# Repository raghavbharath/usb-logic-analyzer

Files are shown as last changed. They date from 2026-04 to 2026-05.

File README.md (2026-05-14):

# ECE692 Final Project - USB Digital Logic Analyzer

Main repository: https://github.com/ragusauce4357/ece692-final-project

**Group Members:** Raghav Bharathan (ragusauce4357), Arnav Revankar (avr34), Gonzalo Villanueva, William Dougherty (Will35084), Bryan Galecio (bryangalecio04)

This project is a custom USB logic analyzer built around two STM32F446RE Nucleo boards, developed as our final project for ECE 692 at NJIT. The system captures digital signals from an external device under test, decodes UART, SPI, I2C, and CAN protocols using a Go signal decoder, and visualizes the results in real time through a Python GUI.

## How It Works

The transmitter Nucleo generates test signals over UART, SPI, I2C, and CAN. The receiver Nucleo samples up to 8 digital channels simultaneously at 1MHz using DMA-driven GPIO capture, packages the raw samples into packets, and streams them to a host PC over USB CDC. A Go application reads the packet stream, decodes UART, SPI, and I2C from the raw samples, and forwards the results to a Python GUI over TCP. CAN frames are decoded inside the STM32 hardware itself by the bxCAN peripheral and forwarded directly. 

## Repository and Branch Structure

Note: This repository is organized across several feature branches, with each of us making contributions in different areas. The `master` branch contains the integrated codebase including the firmware configured for 10kHz sampling over ST-Link USART, which was used during final testing and demonstration. The 1MHz USB CDC configuration and other work can be found in the individual feature branches (`feature/stm32-firmware`, `feature/SignalDecoder`, `feature/GUI`, `feature/PCB`, `feature/3DEnclosure`). The `feature/test` branch contains the final snapshot used during the live demo.

```
firmware-receiver/     # STM32 receiver firmware (STM32CubeIDE)
firmware-transmitter/  # STM32 transmitter firmware
SignalDecoder/         # Go signal decoder application
gui/src/               # Python GUI
PCB/                   # KiCad schematic and PCB layout
enclosure/             # 3D printable STL files
docs/                  # Datasheets and reference manuals
```

### Firmware

The receiver firmware runs on an STM32F446RE at 168MHz. TIM1 generates a 1MHz update event that triggers DMA2 on each tick. The DMA reads the lower byte of GPIOC (PC0-PC7) into a 1024-byte circular ping-pong buffer. When the first half fills, an interrupt fires and the firmware packages bytes 0-511 into a 516-byte logic packet with a 2-byte header, sequence number, and XOR checksum, then sends it over USB CDC. The second half fires the same way. This design keeps sampling continuous with no gaps.

CAN is handled separately. The bxCAN peripheral runs at 500kbps and decodes incoming frames entirely in hardware, delivering a clean frame (ID, DLC, data bytes) to an RX interrupt handler. The firmware packages this into a variable-length CAN packet and sends it over USB CDC alongside the logic packets.

The transmitter firmware runs the same clock config and outputs test signals in a loop every second: UART at 115200 baud, SPI at ~164kHz, I2C to a dummy address (0x52), and a CAN frame with ID 0x123 and payload `0xCAFEBABEDEADBEEF`.

Packet formats:
- Logic: `[0xAA][0xBB][seq][512 bytes][XOR checksum]` = 516 bytes
- CAN: `[0xCC][0xDD][seq][ID_H][ID_L][DLC][0-8 data bytes][XOR checksum]` = variable length

### Go SignalDecoder

The SignalDecoder reads the USB serial stream from the receiver. A `ReadByteStream` goroutine reads into a 1024-byte buffer and pushes raw byte slices into a buffered channel. A `Run` coordinator consumes from the channel, scans for `0xAA 0xBB` or `0xCC 0xDD` headers using a pending accumulation slice to handle packets that span across reads, validates XOR checksums, and detects dropped packets via sequence number wraparound. Logic packets go to the UART, SPI, and I2C decoders. CAN packets are forwarded directly to Python over TCP.

CLI flags: `--port`, `--protocol`, `--pins`, `--duration`

### Python GUI

The GUI launches the Go binary as a subprocess with the appropriate CLI arguments, then connects to its TCP socket to receive decoded data. A background thread parses incoming packets and emits Qt signals to the main thread.

The waveform view shows 8 digital channels plus a synthetic CAN row reconstructed from decoded frame timestamps and DLC. Features include a crosshair cursor, a permanent multi-pair measurement tool with delta-time and frequency readout, a vertical scrollbar, protocol decode annotations color-coded by type, and a CAN decode table. Captures can be saved and loaded as JSON.

Run in simulator mode (no hardware needed, but a few tweaks might need to be made to the code):
```
python gui/src/gui.py --test
```

### PCB

The PCB is a breakout shield that plugs onto both Nucleo boards simultaneously via their morpho headers. It carries a TXS0108E 8-channel bidirectional level shifter for the probe inputs, two SN65HVD230 CAN transceivers (one per Nucleo), per-channel 1kohm series resistors and BAT85 Schottky diodes for overvoltage protection, 4.7kohm I2C pull-ups, a 10-pin probe header, a CANH/CANL screw terminal, and 120ohm CAN termination resistors at each bus end. The schematic is split into receiver and transmitter sub-sheets under a hierarchical root sheet in KiCad.

### Enclosure

3D-printable STL files for a custom enclosure are in `enclosure/`.

## Dependencies

Python:
```
pip install -r gui/src/requirements.txt
```

Go:
```
cd SignalDecoder && go build
```

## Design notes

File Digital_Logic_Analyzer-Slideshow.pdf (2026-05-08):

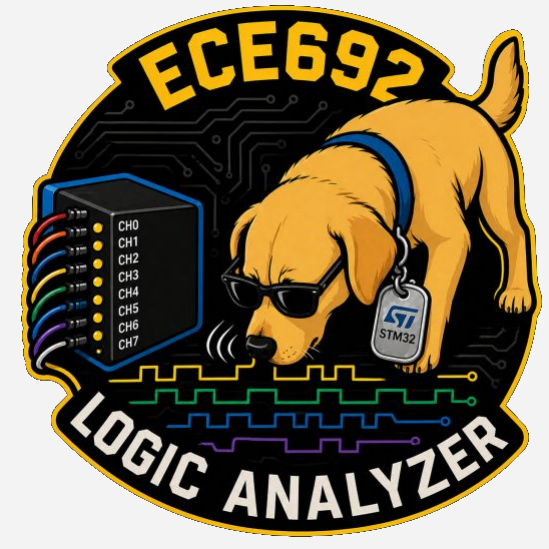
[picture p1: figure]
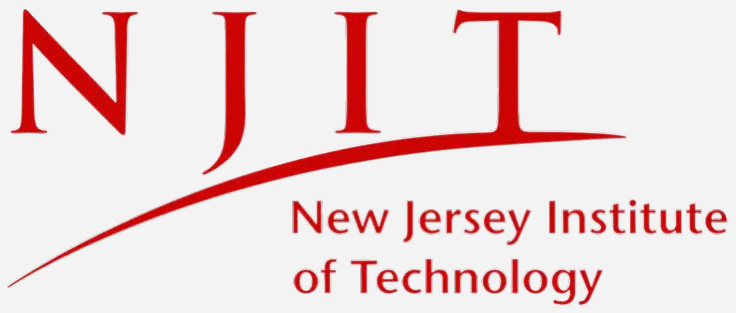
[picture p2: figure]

# Digital Logic Analyzer

By: Arnav Revankar, Gonzalo Villanueva, Raghav Bharathan, William Dougherty, Bryan Galecio

# Agenda

2

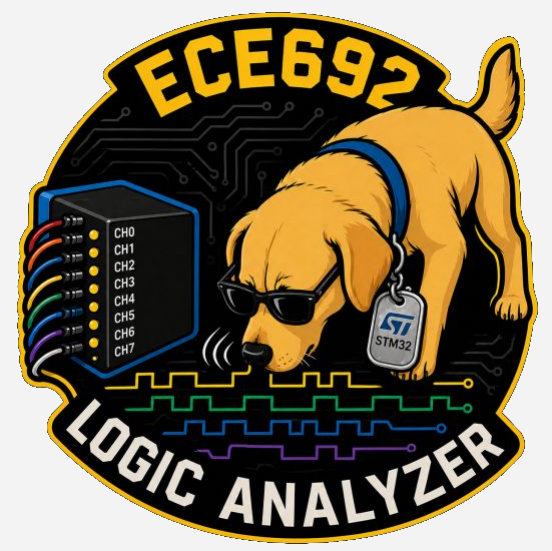
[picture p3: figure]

### - Problem Statement - Project Objectives & Specifications - Components & Cost - System Overview - Code Overview - GUI Overview - Conclusion

# Problem Statement

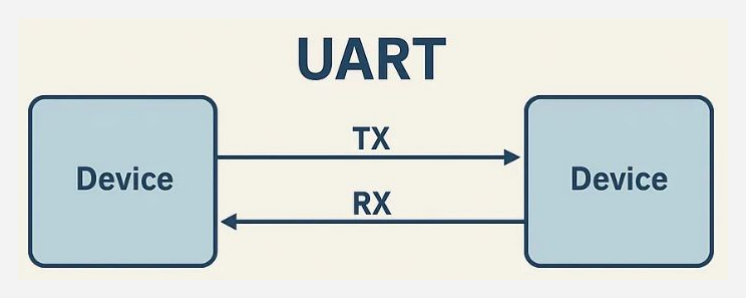
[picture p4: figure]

### - Digital Communication

- UART, SPI, I²C, CAN

### - Challenges within Embedded Systems

- Different protocols use varying frame structures and bit lengths, requiring precise decoding
- Accurate communication depends on strict clocking or synchronization between transmitter and receiver
- Bit mismatches, noise, or misaligned decoding can cause undetected data corruption

### - Digital Logic Analyzer (SOLUTION)

- Tool that captures and visualizes digital signals over time

3

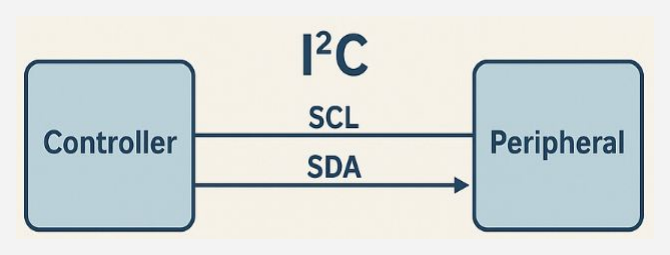
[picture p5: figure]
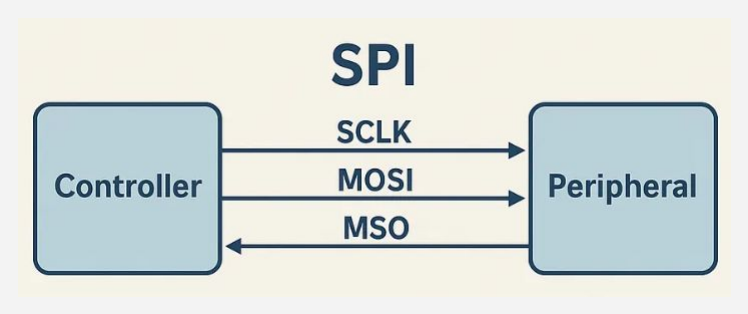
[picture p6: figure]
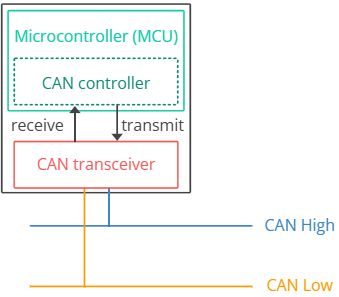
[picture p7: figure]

# Project Objectives & Specifications

- Build an 8-channel Digital Logic Analyzer using GPIO inputs - Use internal timer & DMA to sample signals at a fixed rate, offloading the CPU - Use double buffering to continuously capture and store data without sample loss - Stream data to a PC over USB with basic error detection (sequence numbers + checksum) - Develop a PC GUI for real-time waveform visualization and basic protocol decoding (UART, SPI, I2C, CAN) - Design a PCB layout optimized for low noise, higher sample rate, and system compatibility

4

# Components & Cost

5

Component | Quantity | Cost
NUCLEO-F446RE | 1 | $14.53
SN65HVD230 Can Bus Transceiver | 1 | $2.52
TXS0108E 8-Bit Bi-Directional Level-Shifter | 1 | $1.69
USB-C Socket | 1 | $1.32
Custom PCB | 1 | $9

### Total Cost: $29.06

# System Overview (Block Diagram & Software Pipeline)

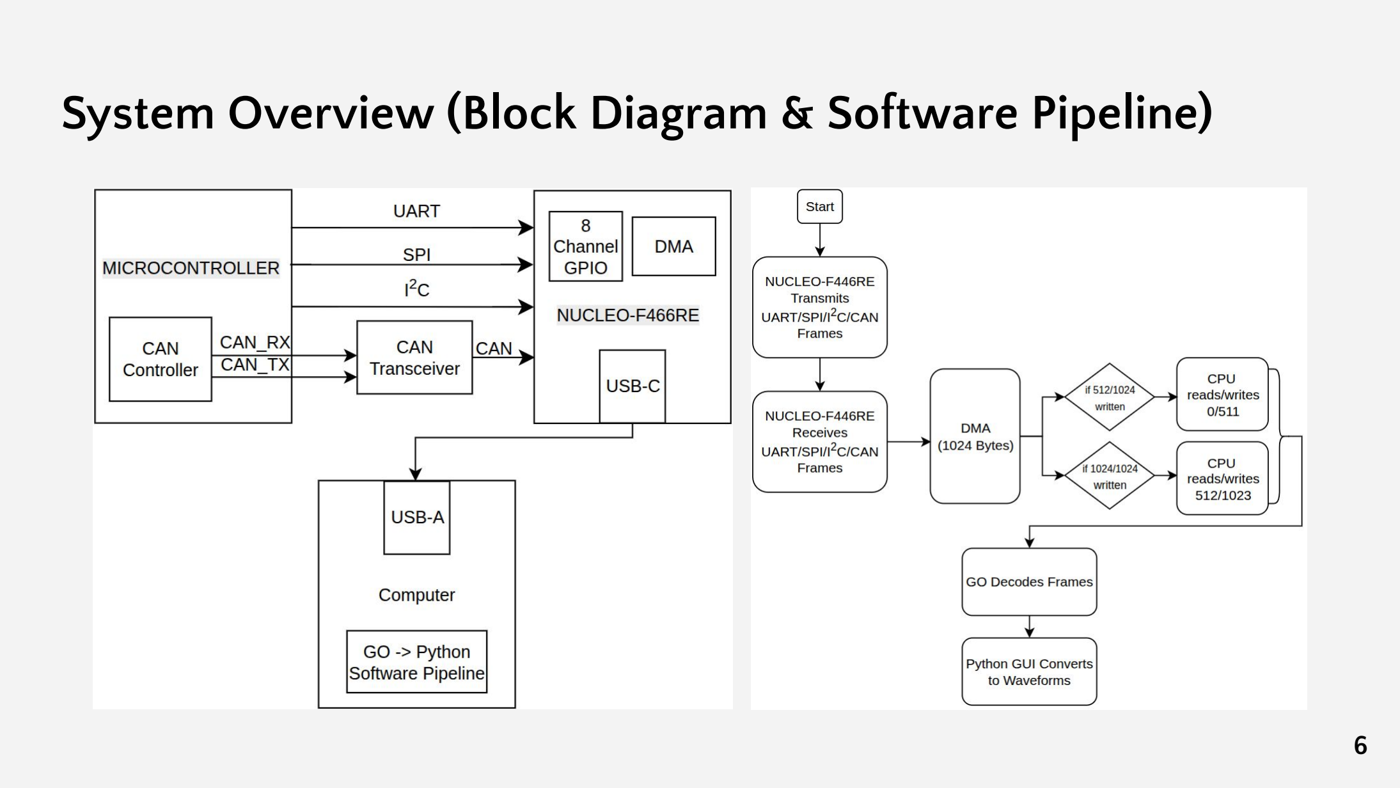
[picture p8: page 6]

6

# System Overview (Schematic)

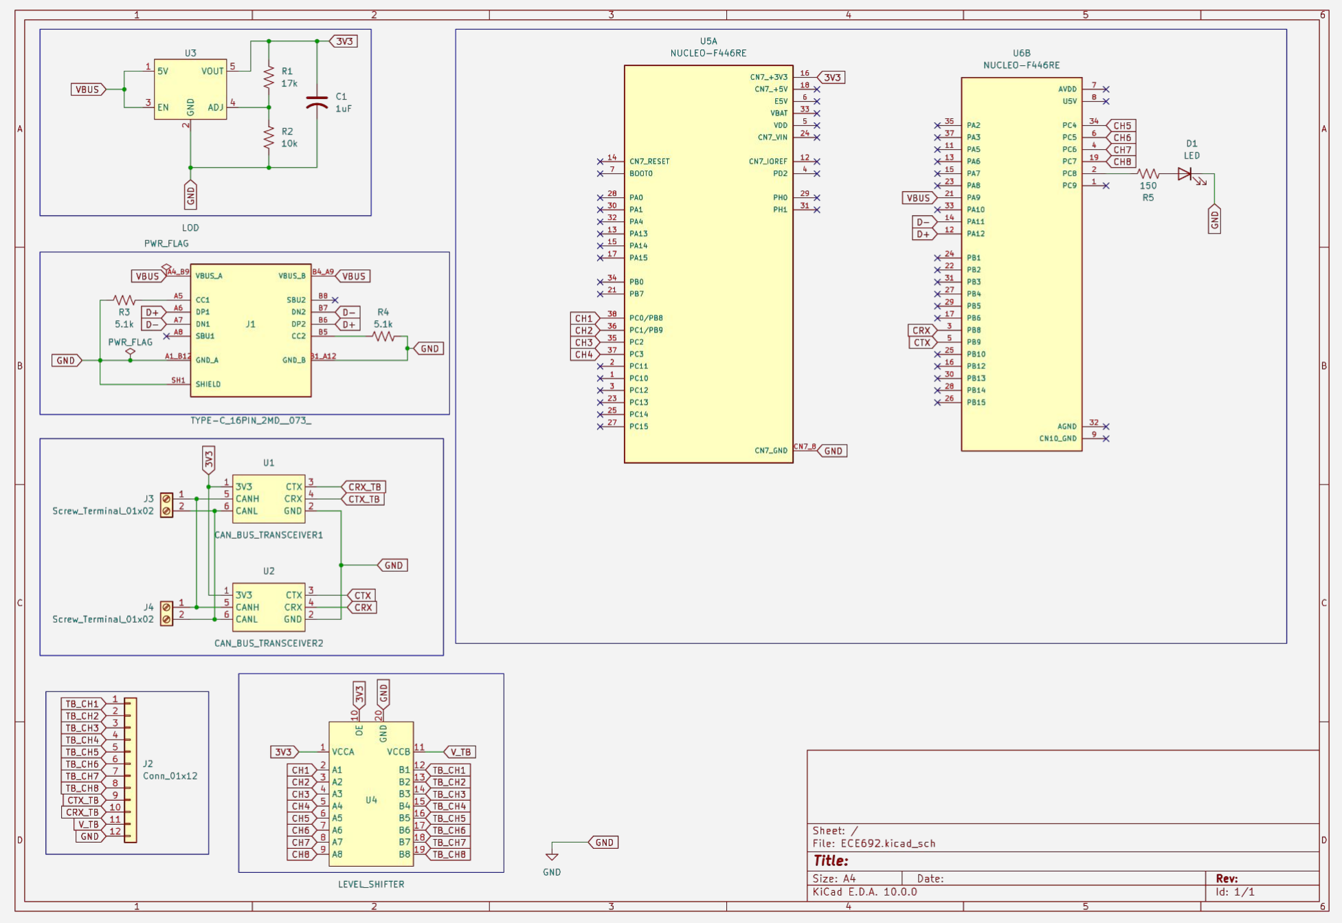
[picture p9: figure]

7

# System Overview (PCB Diagram)

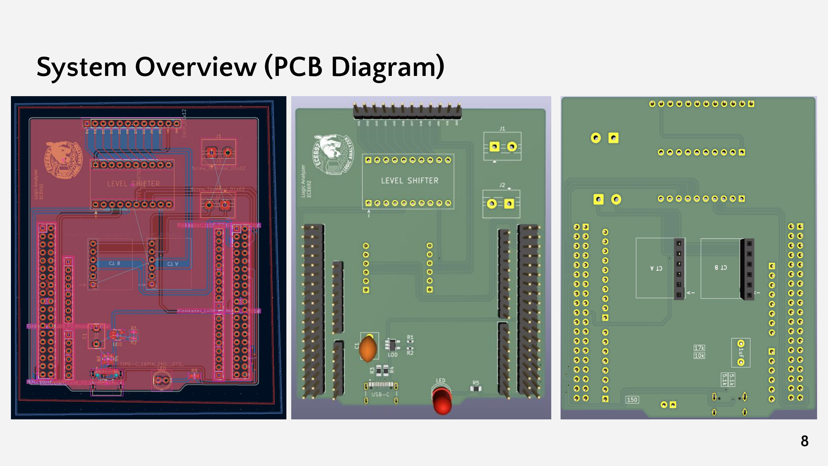
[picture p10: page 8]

8

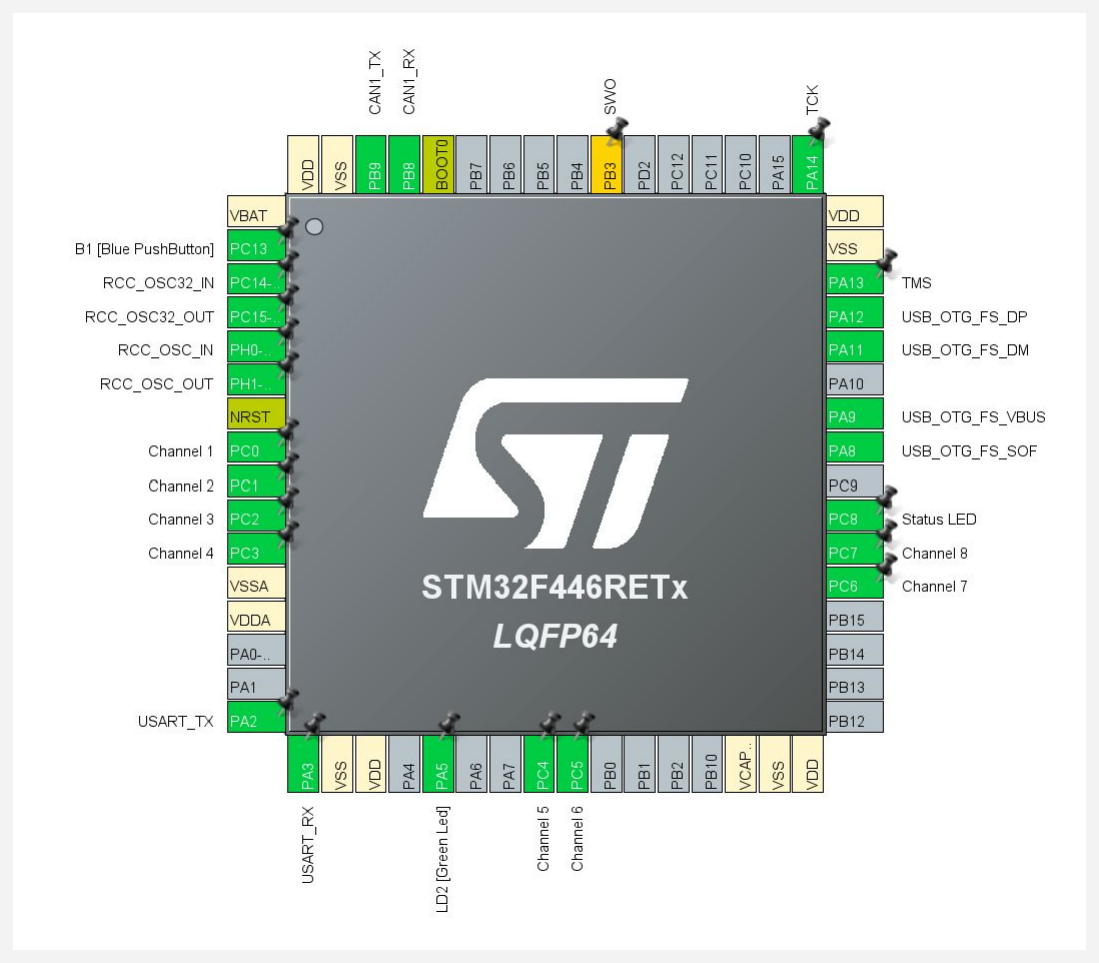
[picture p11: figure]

# STM32 CubeMX Configuration

System Clock
- HSE (8MHz crystal), PLL: PLLM=4, PLLN=168, PLLP=2 → 168MHz HCLK (max)
- APB1 = 42MHz (/4), APB2 = 84 MHz (/2)

TIM1 - Sampling Clock

- Prescaler=99, Period=167 → 10kHz sample rate
- Master output trigger (TRGO) triggers the update for the DMA.

DMA2

- Source: GPIOC→IDR | Destination: dma_buf
- Circular, byte→byte, High priority
- Half and Full transfer interrupts enabled

bxCAN1
- | PSC = 6, BS1 = 11TQ, BS2 = 2TQ → 500kbps, PB8/PB9, RX FIFO0 interrupt is enabled | 9
| NVIC Priorities
| ● DMA2 Stream5: Priority 0 (highest) ● USB: Priority 1 ● bxCAN RX0: Priority 1

# STM32 Sniffer Firmware Pseudocode Overview

CONFIGURE:
GPIO PC0 - PC7: 8-channel digital inputs
TIM1: 10kHz sampling clock
DMA2 Stream5: Circular buffer to store samples USART2: 115200 baud (ST-link to PC)

START TIM1
START DMA
Source: GPIOC input register (all 8 channels)
Destination: Ping-Pong buffer with 2 512 byte Data Chunks = 1024 bytes When the DMA is half-full: flag send_first_half = 1
When the DMA is full: flag send_second_half = 1
LOOP:
IF first half of DMA buffer is ready:
SEND first half of samples to PC
IF second half of DMA buffer is ready:
SEND second half of samples to PC | 10

# STM32 Sniffer Firmware bxCAN Pseudocode Overview

CONFIGURE bxCAN1:

Filter: Accept-all (mask = 0000, bank = 0)

Mode: Normal

START CAN peripheral

Enable RX0 FIFO Interrupt

ON INTERRUPT - if frame received:

READ from FIFO:

StdId → 11-bit CAN ID

DLC → data length (0–8 bytes)

Data[] → payload

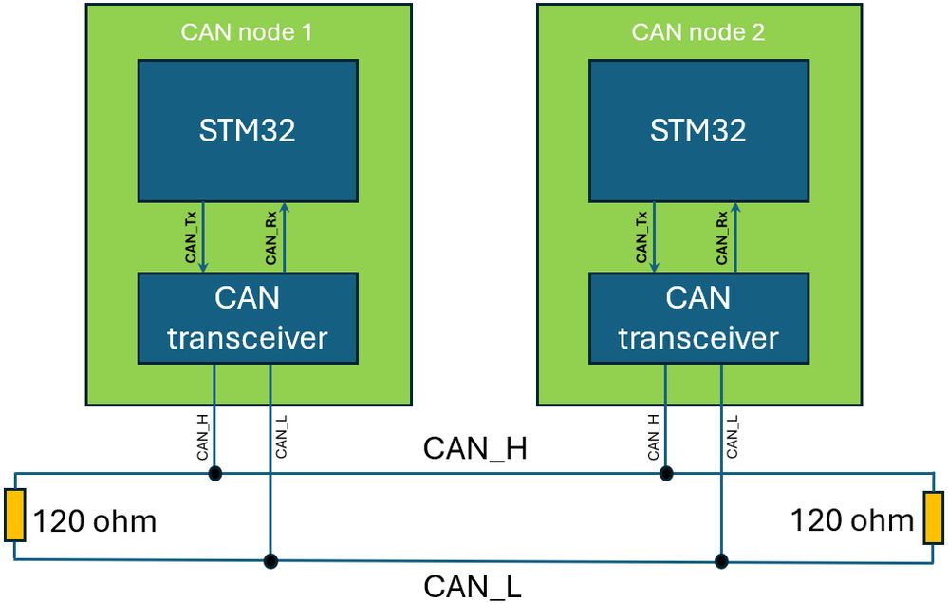
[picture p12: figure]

BUILD packet: [0xCC][0xDD][seq][ID_H][ID_L][DLC][data][XOR checksum]
TRANSMIT over USART2 → PC | 11

# Decoding the Protocols

- For packet decoding, we used Go.
- Packets arrive from the STM via a COM port (COMx or /dev/ttyx) in custom 516 byte format:
- [Header 0xAABB] [Sequence num (0 - 255)] [512 Channel Samples] [XOR Checksum]
- The Go decoder reads these packets off the COM port, and will:
- Validate the checksum (XOR all received bytes)
- Validate the sequence number. If invalid then a packet was dropped.
- Reconstruct the channel waveforms, and decode the chosen signal protocol.
- Currently, UART, I2C, and SPI are supported, and tested with simulated packets
- However, only UART was tested, due to sample rate constraints.

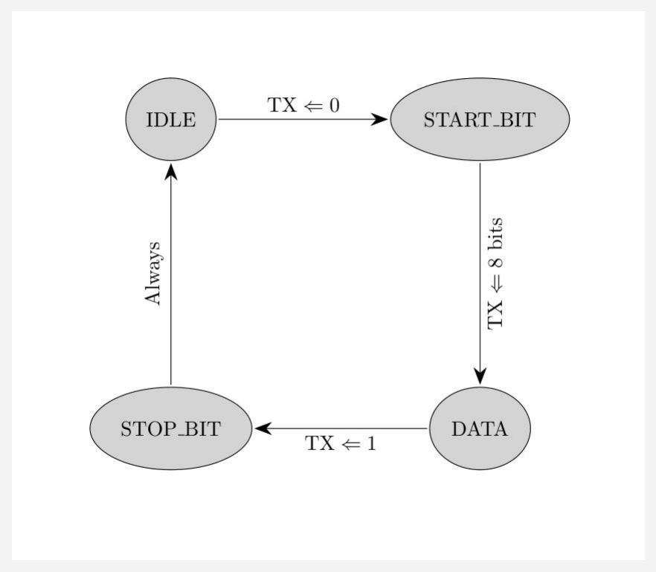
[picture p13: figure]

12

- Waveform data and decoded packets then sent to Python GUI via
network socket.

# GUI Overview

### - Uses: - Python ■ PyQT5 ■ PyQTGraph ■ Numpy ■ Time

13

### Pseudocode:

### - Captures COM port data through Go (transport.py) - Reads packets / parses them (packets.py) - Plots the waveforms next to their corresponding labels(display.py) - Opens an application with logical analyzer tool (gui.py)

# GUI Overview (continued)

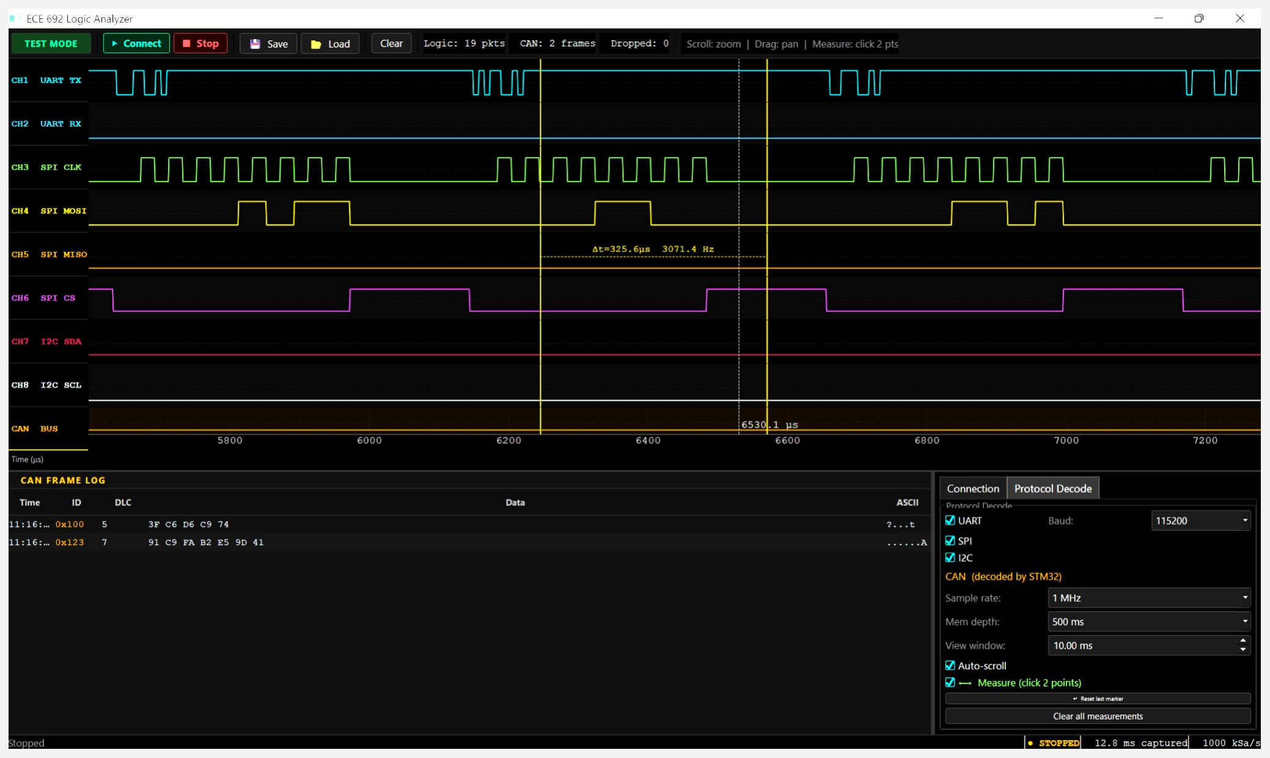
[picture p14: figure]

14

Two main regions: - Top: - Toolbar - Waveforms / Labels - Bottom: - Can Frame Log - Settings Panel - Protocol Decode Panel - Connection Panel - Status Bar

# GUI Overview (continued)

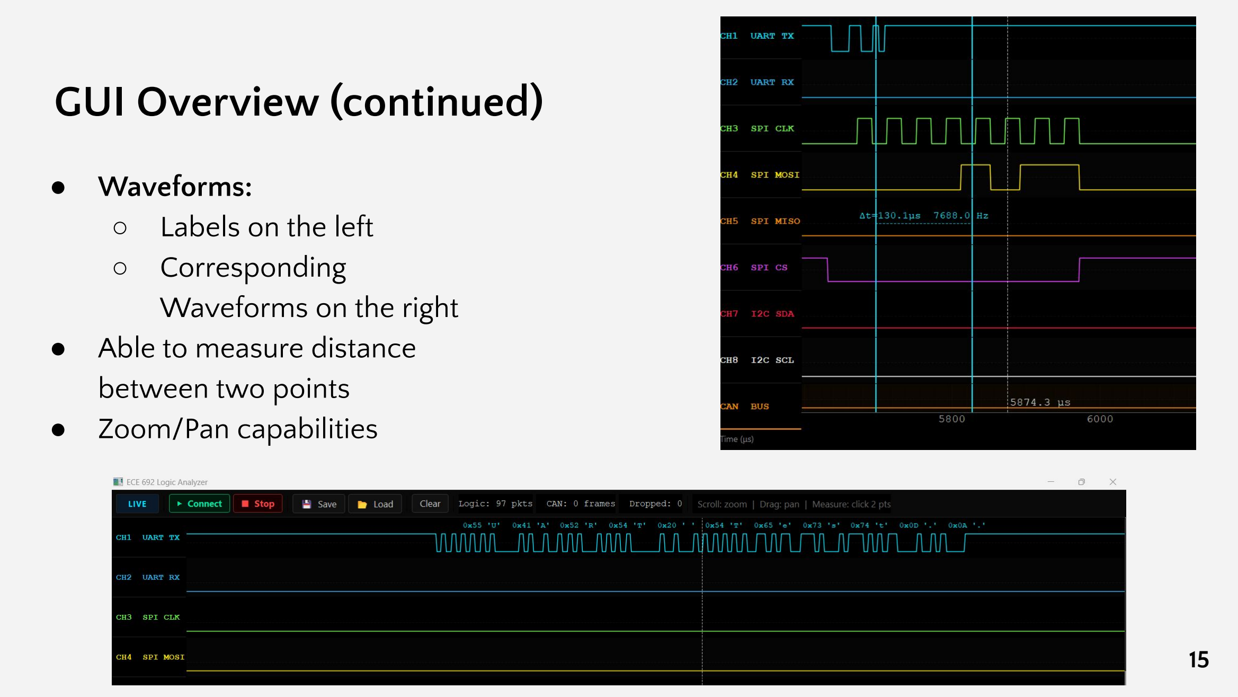
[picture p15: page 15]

15

### - Waveforms: - Labels on the left - Corresponding Waveforms on the right - Able to measure distance between two points - Zoom/Pan capabilities

# Conclusion

### - Challenges

- ST-Link Bottleneck During Prototyping
■ Low throughput caused data transfer issues and incorrect decoding; resolved with custom PCB + improved USB interface

### - Future Improvements

- Switch from ST-Link USART to USB CDC from the PCB connector. This will enable 1MHz sampling and 115200 baud rate for UART decoding, which would reduce noise and provide better accuracy.
- Improve the decoded frame sizing in the GUI and potentially move one of the CAN transceivers outside the PCB for CANH/CANL compatibility.
- Implement compatibility for protocols outside the scope of what we have so far (UART, SPI, I²C, CAN) and also with Sigrok and Pulseview’s byte structure format.

16

# Questions?

17

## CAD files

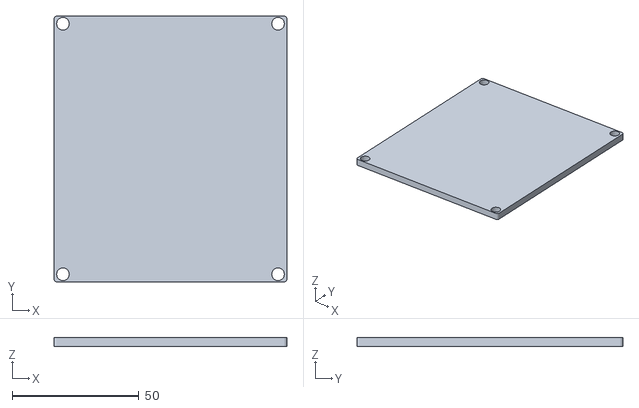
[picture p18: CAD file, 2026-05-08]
enclosure/Lid.stl
92.0 x 105.0 x 3.50

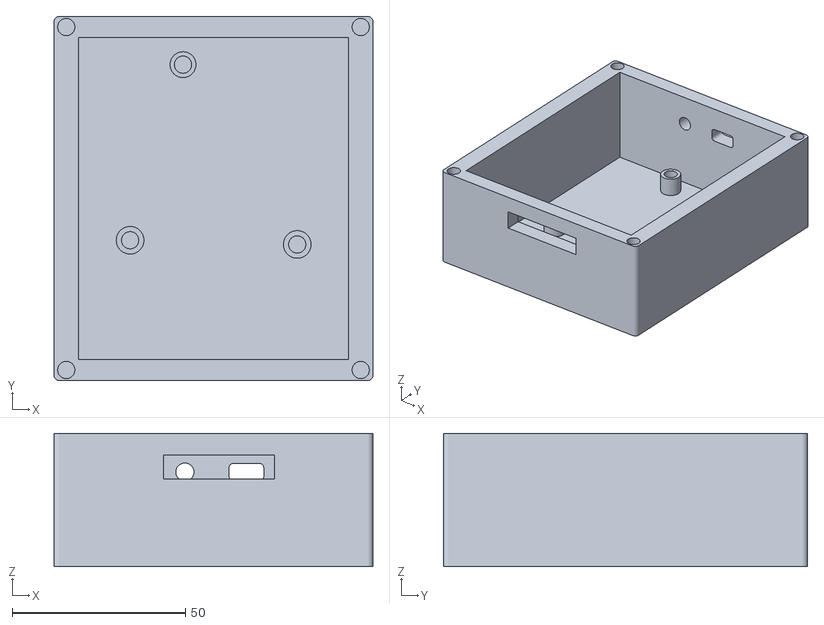
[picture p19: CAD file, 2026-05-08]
enclosure/Enclosure.stl
92.0 x 105.0 x 38.5

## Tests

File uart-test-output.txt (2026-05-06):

PS C:\Users\ragha\OneDrive\Desktop\ECE692-Final-Project\SignalDecoder> go run . --port COM4 --protocol UART --pins tx1rx2 --sr 10000 --duration 5000 --baud 2400
2026/05/06 01:35:33 [GetConfig]: Parsing arguments...
2026/05/06 01:35:33 [parsePins]: Parsing pins argument...
2026/05/06 01:35:33 [parseUART]: Parsing UART pins...
2026/05/06 01:35:33 [parseUART]: Using channels 1, 2, for tx and rx
2026/05/06 01:35:33 [parseUART]: Completed UART pin parsing
2026/05/06 01:35:33 [GetConfig]: CLI argument error checking complete.
2026/05/06 01:35:33 [print] Current configuration:
2026/05/06 01:35:33 [print]   Port:        COM4
2026/05/06 01:35:33 [print]   Duration:    5000.000000
2026/05/06 01:35:33 [print]   Sample Rate: 0x2710
2026/05/06 01:35:33 [print]   Protocol:    1
2026/05/06 01:35:33 [print]   Pins:        0x1200
2026/05/06 01:35:33 [Run]: Running for 5000 ms
2026/05/06 01:35:33 [ReadByteStream]: Opened port.
2026/05/06 01:35:33 [ReadByteStream]: Started streaming from COM4...
2026/05/06 01:35:33 [parseLogicPacket]: Logic packet seq=179
2026/05/06 01:35:33 [DecodeUART]: Beginning UART Decoding...
2026/05/06 01:35:33 [DecodeUART]: UART Decoding complete
2026/05/06 01:35:33 [parseLogicPacket]: Logic packet seq=180
2026/05/06 01:35:33 [DecodeUART]: Beginning UART Decoding...
2026/05/06 01:35:33 [DecodeUART]: UART Decoding complete
2026/05/06 01:35:34 [parseLogicPacket]: Logic packet seq=181
2026/05/06 01:35:34 [DecodeUART]: Beginning UART Decoding...
2026/05/06 01:35:34 [DecodeUART]: UART Decoding complete
2026/05/06 01:35:34 [parseLogicPacket]: Logic packet seq=182
2026/05/06 01:35:34 [DecodeUART]: Beginning UART Decoding...
2026/05/06 01:35:34 [DecodeUART]: UART Decoding complete
2026/05/06 01:35:34 [parseLogicPacket]: Logic packet seq=183
2026/05/06 01:35:34 [DecodeUART]: Beginning UART Decoding...
2026/05/06 01:35:34 [DecodeUART]: UART Decoding complete
2026/05/06 01:35:34 [parseLogicPacket]: Logic packet seq=184
2026/05/06 01:35:34 [DecodeUART]: Beginning UART Decoding...
2026/05/06 01:35:34 [DecodeUART]: UART Decoding complete
2026/05/06 01:35:34 [parseLogicPacket]: Logic packet seq=185
2026/05/06 01:35:34 [DecodeUART]: Beginning UART Decoding...
2026/05/06 01:35:34 [DecodeUART]: UART Decoding complete
2026/05/06 01:35:34 [parseLogicPacket]: Logic packet seq=186
2026/05/06 01:35:34 [DecodeUART]: Beginning UART Decoding...
2026/05/06 01:35:34 [DecodeUART]: UART Decoding complete
2026/05/06 01:35:34 [parseLogicPacket]: Logic packet seq=187
2026/05/06 01:35:34 [DecodeUART]: Beginning UART Decoding...
2026/05/06 01:35:34 [DecodeUART]: UART Decoding complete
2026/05/06 01:35:34 [parseLogicPacket]: Logic packet seq=188
2026/05/06 01:35:34 [DecodeUART]: Beginning UART Decoding...
2026/05/06 01:35:34 [DecodeUART]: UART Decoding complete
2026/05/06 01:35:34 [parseLogicPacket]: Logic packet seq=189
2026/05/06 01:35:34 [DecodeUART]: Beginning UART Decoding...
2026/05/06 01:35:34 [DecodeUART]: UART Decoding complete
2026/05/06 01:35:34 [Run]: UART transfer over tx: t=521000us TX=0x55
2026/05/06 01:35:34 [Run]: UART transfer over tx: t=525200us TX=0x41
2026/05/06 01:35:34 [Run]: UART transfer over tx: t=529300us TX=0x52
2026/05/06 01:35:34 [Run]: UART transfer over tx: t=533500us TX=0x54
2026/05/06 01:35:34 [Run]: UART transfer over tx: t=537700us TX=0x20
2026/05/06 01:35:34 [Run]: UART transfer over tx: t=541800us TX=0x54
2026/05/06 01:35:34 [Run]: UART transfer over tx: t=546000us TX=0x65
2026/05/06 01:35:34 [Run]: UART transfer over tx: t=550200us TX=0x73
2026/05/06 01:35:34 [Run]: UART transfer over tx: t=554300us TX=0x74
2026/05/06 01:35:34 [Run]: UART transfer over tx: t=558500us TX=0x0D
2026/05/06 01:35:34 [Run]: UART transfer over tx: t=562700us TX=0x0A
2026/05/06 01:35:34 [parseLogicPacket]: Logic packet seq=190
2026/05/06 01:35:34 [DecodeUART]: Beginning UART Decoding...
2026/05/06 01:35:34 [DecodeUART]: UART Decoding complete
2026/05/06 01:35:34 [parseLogicPacket]: Logic packet seq=191
2026/05/06 01:35:34 [DecodeUART]: Beginning UART Decoding...
2026/05/06 01:35:34 [DecodeUART]: UART Decoding complete
2026/05/06 01:35:34 [parseLogicPacket]: Logic packet seq=192
2026/05/06 01:35:34 [DecodeUART]: Beginning UART Decoding...
2026/05/06 01:35:34 [DecodeUART]: UART Decoding complete
2026/05/06 01:35:34 [parseLogicPacket]: Logic packet seq=193
2026/05/06 01:35:34 [DecodeUART]: Beginning UART Decoding...
2026/05/06 01:35:34 [DecodeUART]: UART Decoding complete
2026/05/06 01:35:34 [parseLogicPacket]: Logic packet seq=194
2026/05/06 01:35:34 [DecodeUART]: Beginning UART Decoding...
2026/05/06 01:35:34 [DecodeUART]: UART Decoding complete
2026/05/06 01:35:34 [parseLogicPacket]: Logic packet seq=195
2026/05/06 01:35:34 [DecodeUART]: Beginning UART Decoding...
2026/05/06 01:35:34 [DecodeUART]: UART Decoding complete
2026/05/06 01:35:34 [parseLogicPacket]: Logic packet seq=196
2026/05/06 01:35:34 [DecodeUART]: Beginning UART Decoding...
2026/05/06 01:35:34 [DecodeUART]: UART Decoding complete
2026/05/06 01:35:34 [parseLogicPacket]: Logic packet seq=197
2026/05/06 01:35:34 [DecodeUART]: Beginning UART Decoding...
2026/05/06 01:35:34 [DecodeUART]: UART Decoding complete
2026/05/06 01:35:34 [parseLogicPacket]: Logic packet seq=198
2026/05/06 01:35:34 [DecodeUART]: Beginning UART Decoding...
2026/05/06 01:35:34 [DecodeUART]: UART Decoding complete
2026/05/06 01:35:34 [parseLogicPacket]: Logic packet seq=199
2026/05/06 01:35:34 [DecodeUART]: Beginning UART Decoding...
2026/05/06 01:35:34 [DecodeUART]: UART Decoding complete
2026/05/06 01:35:35 [parseLogicPacket]: Logic packet seq=200
2026/05/06 01:35:35 [DecodeUART]: Beginning UART Decoding...
2026/05/06 01:35:35 [DecodeUART]: UART Decoding complete
2026/05/06 01:35:35 [parseLogicPacket]: Logic packet seq=201
2026/05/06 01:35:35 [DecodeUART]: Beginning UART Decoding...
2026/05/06 01:35:35 [DecodeUART]: UART Decoding complete
2026/05/06 01:35:35 [parseLogicPacket]: Logic packet seq=202
2026/05/06 01:35:35 [DecodeUART]: Beginning UART Decoding...
2026/05/06 01:35:35 [DecodeUART]: UART Decoding complete
2026/05/06 01:35:35 [parseLogicPacket]: Logic packet seq=203
2026/05/06 01:35:35 [DecodeUART]: Beginning UART Decoding...
2026/05/06 01:35:35 [DecodeUART]: UART Decoding complete
2026/05/06 01:35:35 [parseLogicPacket]: Logic packet seq=204
2026/05/06 01:35:35 [DecodeUART]: Beginning UART Decoding...
2026/05/06 01:35:35 [DecodeUART]: UART Decoding complete
2026/05/06 01:35:35 [parseLogicPacket]: Logic packet seq=205
2026/05/06 01:35:35 [DecodeUART]: Beginning UART Decoding...
2026/05/06 01:35:35 [DecodeUART]: UART Decoding complete
2026/05/06 01:35:35 [parseLogicPacket]: Logic packet seq=206
2026/05/06 01:35:35 [DecodeUART]: Beginning UART Decoding...
2026/05/06 01:35:35 [DecodeUART]: UART Decoding complete
2026/05/06 01:35:35 [parseLogicPacket]: Logic packet seq=207
2026/05/06 01:35:35 [DecodeUART]: Beginning UART Decoding...
2026/05/06 01:35:35 [DecodeUART]: UART Decoding complete
2026/05/06 01:35:35 [parseLogicPacket]: Logic packet seq=208
2026/05/06 01:35:35 [DecodeUART]: Beginning UART Decoding...
2026/05/06 01:35:35 [DecodeUART]: UART Decoding complete
2026/05/06 01:35:35 [parseLogicPacket]: Logic packet seq=209
2026/05/06 01:35:35 [DecodeUART]: Beginning UART Decoding...
2026/05/06 01:35:35 [DecodeUART]: UART Decoding complete
2026/05/06 01:35:35 [parseLogicPacket]: Logic packet seq=210
2026/05/06 01:35:35 [DecodeUART]: Beginning UART Decoding...
2026/05/06 01:35:35 [DecodeUART]: UART Decoding complete
2026/05/06 01:35:35 [Run]: UART transfer over tx: t=1593900us TX=0x55
2026/05/06 01:35:35 [Run]: UART transfer over tx: t=1598100us TX=0x41
2026/05/06 01:35:35 [Run]: UART transfer over tx: t=1602300us TX=0x52
2026/05/06 01:35:35 [Run]: UART transfer over tx: t=1606400us TX=0x54
2026/05/06 01:35:35 [Run]: UART transfer over tx: t=1610600us TX=0x20
2026/05/06 01:35:35 [Run]: UART transfer over tx: t=1614800us TX=0x54
2026/05/06 01:35:35 [Run]: UART transfer over tx: t=1618900us TX=0x65
2026/05/06 01:35:35 [Run]: UART transfer over tx: t=1623100us TX=0x73
2026/05/06 01:35:35 [Run]: UART transfer over tx: t=1627300us TX=0x74
2026/05/06 01:35:35 [Run]: UART transfer over tx: t=1631400us TX=0x0D
2026/05/06 01:35:35 [Run]: UART transfer over tx: t=1635600us TX=0x0A
2026/05/06 01:35:35 [parseLogicPacket]: Logic packet seq=211
2026/05/06 01:35:35 [DecodeUART]: Beginning UART Decoding...
2026/05/06 01:35:35 [DecodeUART]: UART Decoding complete
2026/05/06 01:35:35 [parseLogicPacket]: Logic packet seq=212
2026/05/06 01:35:35 [DecodeUART]: Beginning UART Decoding...
2026/05/06 01:35:35 [DecodeUART]: UART Decoding complete
2026/05/06 01:35:35 [parseLogicPacket]: Logic packet seq=213
2026/05/06 01:35:35 [DecodeUART]: Beginning UART Decoding...
2026/05/06 01:35:35 [DecodeUART]: UART Decoding complete
2026/05/06 01:35:35 [parseLogicPacket]: Logic packet seq=214
2026/05/06 01:35:35 [DecodeUART]: Beginning UART Decoding...
2026/05/06 01:35:35 [DecodeUART]: UART Decoding complete
2026/05/06 01:35:35 [parseLogicPacket]: Logic packet seq=215
2026/05/06 01:35:35 [DecodeUART]: Beginning UART Decoding...
2026/05/06 01:35:35 [DecodeUART]: UART Decoding complete
2026/05/06 01:35:35 [parseLogicPacket]: Logic packet seq=216
2026/05/06 01:35:35 [DecodeUART]: Beginning UART Decoding...
2026/05/06 01:35:35 [DecodeUART]: UART Decoding complete
2026/05/06 01:35:35 [parseLogicPacket]: Logic packet seq=217
2026/05/06 01:35:35 [DecodeUART]: Beginning UART Decoding...
2026/05/06 01:35:35 [DecodeUART]: UART Decoding complete
2026/05/06 01:35:35 [parseLogicPacket]: Logic packet seq=218
2026/05/06 01:35:35 [DecodeUART]: Beginning UART Decoding...
2026/05/06 01:35:35 [DecodeUART]: UART Decoding complete
2026/05/06 01:35:35 [parseLogicPacket]: Logic packet seq=219
2026/05/06 01:35:35 [DecodeUART]: Beginning UART Decoding...
2026/05/06 01:35:35 [DecodeUART]: UART Decoding complete
2026/05/06 01:35:36 [parseLogicPacket]: Logic packet seq=220
2026/05/06 01:35:36 [DecodeUART]: Beginning UART Decoding...
2026/05/06 01:35:36 [DecodeUART]: UART Decoding complete
2026/05/06 01:35:36 [parseLogicPacket]: Logic packet seq=221
2026/05/06 01:35:36 [DecodeUART]: Beginning UART Decoding...
2026/05/06 01:35:36 [DecodeUART]: UART Decoding complete
2026/05/06 01:35:36 [parseLogicPacket]: Logic packet seq=222
2026/05/06 01:35:36 [DecodeUART]: Beginning UART Decoding...
2026/05/06 01:35:36 [DecodeUART]: UART Decoding complete
2026/05/06 01:35:36 [parseLogicPacket]: Logic packet seq=223
2026/05/06 01:35:36 [DecodeUART]: Beginning UART Decoding...
2026/05/06 01:35:36 [DecodeUART]: UART Decoding complete
2026/05/06 01:35:36 [parseLogicPacket]: Logic packet seq=224
2026/05/06 01:35:36 [DecodeUART]: Beginning UART Decoding...
2026/05/06 01:35:36 [DecodeUART]: UART Decoding complete
2026/05/06 01:35:36 [parseLogicPacket]: Logic packet seq=225
2026/05/06 01:35:36 [DecodeUART]: Beginning UART Decoding...
2026/05/06 01:35:36 [DecodeUART]: UART Decoding complete
2026/05/06 01:35:36 [parseLogicPacket]: Logic packet seq=226
2026/05/06 01:35:36 [DecodeUART]: Beginning UART Decoding...
2026/05/06 01:35:36 [DecodeUART]: UART Decoding complete
2026/05/06 01:35:36 [parseLogicPacket]: Logic packet seq=227
2026/05/06 01:35:36 [DecodeUART]: Beginning UART Decoding...
2026/05/06 01:35:36 [DecodeUART]: UART Decoding complete
2026/05/06 01:35:36 [parseLogicPacket]: Logic packet seq=228
2026/05/06 01:35:36 [DecodeUART]: Beginning UART Decoding...
2026/05/06 01:35:36 [DecodeUART]: UART Decoding complete
2026/05/06 01:35:36 [parseLogicPacket]: Logic packet seq=229
2026/05/06 01:35:36 [DecodeUART]: Beginning UART Decoding...
2026/05/06 01:35:36 [DecodeUART]: UART Decoding complete
2026/05/06 01:35:36 [parseLogicPacket]: Logic packet seq=230
2026/05/06 01:35:36 [DecodeUART]: Beginning UART Decoding...
2026/05/06 01:35:36 [DecodeUART]: UART Decoding complete
2026/05/06 01:35:36 [parseLogicPacket]: Logic packet seq=231
2026/05/06 01:35:36 [DecodeUART]: Beginning UART Decoding...
2026/05/06 01:35:36 [DecodeUART]: UART Decoding complete
2026/05/06 01:35:36 [Run]: UART transfer over tx: t=2666900us TX=0x55
2026/05/06 01:35:36 [Run]: UART transfer over tx: t=2671000us TX=0x41
2026/05/06 01:35:36 [Run]: UART transfer over tx: t=2675200us TX=0x52
2026/05/06 01:35:36 [Run]: UART transfer over tx: t=2679400us TX=0x54
2026/05/06 01:35:36 [Run]: UART transfer over tx: t=2683500us TX=0x20
2026/05/06 01:35:36 [Run]: UART transfer over tx: t=2687700us TX=0x54
2026/05/06 01:35:36 [Run]: UART transfer over tx: t=2691900us TX=0x65
2026/05/06 01:35:36 [Run]: UART transfer over tx: t=2696000us TX=0x73
2026/05/06 01:35:36 [Run]: UART transfer over tx: t=2700200us TX=0x74
2026/05/06 01:35:36 [Run]: UART transfer over tx: t=2704400us TX=0x0D
2026/05/06 01:35:36 [Run]: UART transfer over tx: t=2708500us TX=0x0A
2026/05/06 01:35:36 [parseLogicPacket]: Logic packet seq=232
2026/05/06 01:35:36 [DecodeUART]: Beginning UART Decoding...
2026/05/06 01:35:36 [DecodeUART]: UART Decoding complete
2026/05/06 01:35:36 [parseLogicPacket]: Logic packet seq=233
2026/05/06 01:35:36 [DecodeUART]: Beginning UART Decoding...
2026/05/06 01:35:36 [DecodeUART]: UART Decoding complete
2026/05/06 01:35:36 [parseLogicPacket]: Logic packet seq=234
2026/05/06 01:35:36 [DecodeUART]: Beginning UART Decoding...
2026/05/06 01:35:36 [DecodeUART]: UART Decoding complete
2026/05/06 01:35:36 [parseLogicPacket]: Logic packet seq=235
2026/05/06 01:35:36 [DecodeUART]: Beginning UART Decoding...
2026/05/06 01:35:36 [DecodeUART]: UART Decoding complete
2026/05/06 01:35:36 [parseLogicPacket]: Logic packet seq=236
2026/05/06 01:35:36 [DecodeUART]: Beginning UART Decoding...
2026/05/06 01:35:36 [DecodeUART]: UART Decoding complete
2026/05/06 01:35:36 [parseLogicPacket]: Logic packet seq=237
2026/05/06 01:35:36 [DecodeUART]: Beginning UART Decoding...
2026/05/06 01:35:36 [DecodeUART]: UART Decoding complete
2026/05/06 01:35:36 [parseLogicPacket]: Logic packet seq=238
2026/05/06 01:35:36 [DecodeUART]: Beginning UART Decoding...
2026/05/06 01:35:36 [DecodeUART]: UART Decoding complete
2026/05/06 01:35:37 [parseLogicPacket]: Logic packet seq=239
2026/05/06 01:35:37 [DecodeUART]: Beginning UART Decoding...
2026/05/06 01:35:37 [DecodeUART]: UART Decoding complete
2026/05/06 01:35:37 [parseLogicPacket]: Logic packet seq=240
2026/05/06 01:35:37 [DecodeUART]: Beginning UART Decoding...
2026/05/06 01:35:37 [DecodeUART]: UART Decoding complete
2026/05/06 01:35:37 [parseLogicPacket]: Logic packet seq=241
2026/05/06 01:35:37 [DecodeUART]: Beginning UART Decoding...
2026/05/06 01:35:37 [DecodeUART]: UART Decoding complete
2026/05/06 01:35:37 [parseLogicPacket]: Logic packet seq=242
2026/05/06 01:35:37 [DecodeUART]: Beginning UART Decoding...
2026/05/06 01:35:37 [DecodeUART]: UART Decoding complete
2026/05/06 01:35:37 [parseLogicPacket]: Logic packet seq=243
2026/05/06 01:35:37 [DecodeUART]: Beginning UART Decoding...
2026/05/06 01:35:37 [DecodeUART]: UART Decoding complete
2026/05/06 01:35:37 [parseLogicPacket]: Logic packet seq=244
2026/05/06 01:35:37 [DecodeUART]: Beginning UART Decoding...
2026/05/06 01:35:37 [DecodeUART]: UART Decoding complete
2026/05/06 01:35:37 [parseLogicPacket]: Logic packet seq=245
2026/05/06 01:35:37 [DecodeUART]: Beginning UART Decoding...
2026/05/06 01:35:37 [DecodeUART]: UART Decoding complete
2026/05/06 01:35:37 [parseLogicPacket]: Logic packet seq=246
2026/05/06 01:35:37 [DecodeUART]: Beginning UART Decoding...
2026/05/06 01:35:37 [DecodeUART]: UART Decoding complete
2026/05/06 01:35:37 [parseLogicPacket]: Logic packet seq=247
2026/05/06 01:35:37 [DecodeUART]: Beginning UART Decoding...
2026/05/06 01:35:37 [DecodeUART]: UART Decoding complete
2026/05/06 01:35:37 [parseLogicPacket]: Logic packet seq=248
2026/05/06 01:35:37 [DecodeUART]: Beginning UART Decoding...
2026/05/06 01:35:37 [DecodeUART]: UART Decoding complete
2026/05/06 01:35:37 [parseLogicPacket]: Logic packet seq=249
2026/05/06 01:35:37 [DecodeUART]: Beginning UART Decoding...
2026/05/06 01:35:37 [DecodeUART]: UART Decoding complete
2026/05/06 01:35:37 [parseLogicPacket]: Logic packet seq=250
2026/05/06 01:35:37 [DecodeUART]: Beginning UART Decoding...
2026/05/06 01:35:37 [DecodeUART]: UART Decoding complete
2026/05/06 01:35:37 [parseLogicPacket]: Logic packet seq=251
2026/05/06 01:35:37 [DecodeUART]: Beginning UART Decoding...
2026/05/06 01:35:37 [DecodeUART]: UART Decoding complete
2026/05/06 01:35:37 [parseLogicPacket]: Logic packet seq=252
2026/05/06 01:35:37 [DecodeUART]: Beginning UART Decoding...
2026/05/06 01:35:37 [DecodeUART]: UART Decoding complete
2026/05/06 01:35:37 [Run]: UART transfer over tx: t=3741500us TX=0x55
2026/05/06 01:35:37 [Run]: UART transfer over tx: t=3747300us TX=0x49
2026/05/06 01:35:37 [Run]: UART transfer over tx: t=3751400us TX=0x51
2026/05/06 01:35:37 [Run]: UART transfer over tx: t=3755600us TX=0x81
2026/05/06 01:35:37 [Run]: UART transfer over tx: t=3760600us TX=0x54
2026/05/06 01:35:37 [Run]: UART transfer over tx: t=3764800us TX=0x65
2026/05/06 01:35:37 [Run]: UART transfer over tx: t=3768900us TX=0x73
2026/05/06 01:35:37 [Run]: UART transfer over tx: t=3773100us TX=0x74
2026/05/06 01:35:37 [Run]: UART transfer over tx: t=3777300us TX=0x0D
2026/05/06 01:35:37 [Run]: UART transfer over tx: t=3781400us TX=0x0A
2026/05/06 01:35:37 [parseLogicPacket]: Logic packet seq=253
2026/05/06 01:35:37 [DecodeUART]: Beginning UART Decoding...
2026/05/06 01:35:37 [DecodeUART]: UART Decoding complete
2026/05/06 01:35:37 [parseLogicPacket]: Logic packet seq=254
2026/05/06 01:35:37 [DecodeUART]: Beginning UART Decoding...
2026/05/06 01:35:37 [DecodeUART]: UART Decoding complete
2026/05/06 01:35:37 [parseLogicPacket]: Logic packet seq=255
2026/05/06 01:35:37 [DecodeUART]: Beginning UART Decoding...
2026/05/06 01:35:37 [DecodeUART]: UART Decoding complete
2026/05/06 01:35:37 [parseLogicPacket]: Logic packet seq=0
2026/05/06 01:35:37 [DecodeUART]: Beginning UART Decoding...
2026/05/06 01:35:37 [DecodeUART]: UART Decoding complete
2026/05/06 01:35:37 [parseLogicPacket]: Logic packet seq=1
2026/05/06 01:35:37 [DecodeUART]: Beginning UART Decoding...
2026/05/06 01:35:37 [DecodeUART]: UART Decoding complete
2026/05/06 01:35:37 [parseLogicPacket]: Logic packet seq=2
2026/05/06 01:35:37 [DecodeUART]: Beginning UART Decoding...
2026/05/06 01:35:37 [DecodeUART]: UART Decoding complete
2026/05/06 01:35:38 [parseLogicPacket]: Logic packet seq=3
2026/05/06 01:35:38 [DecodeUART]: Beginning UART Decoding...
2026/05/06 01:35:38 [DecodeUART]: UART Decoding complete
2026/05/06 01:35:38 [parseLogicPacket]: Logic packet seq=4
2026/05/06 01:35:38 [DecodeUART]: Beginning UART Decoding...
2026/05/06 01:35:38 [DecodeUART]: UART Decoding complete
2026/05/06 01:35:38 [parseLogicPacket]: Logic packet seq=5
2026/05/06 01:35:38 [DecodeUART]: Beginning UART Decoding...
2026/05/06 01:35:38 [DecodeUART]: UART Decoding complete
2026/05/06 01:35:38 [parseLogicPacket]: Logic packet seq=6
2026/05/06 01:35:38 [DecodeUART]: Beginning UART Decoding...
2026/05/06 01:35:38 [DecodeUART]: UART Decoding complete
2026/05/06 01:35:38 [parseLogicPacket]: Logic packet seq=7
2026/05/06 01:35:38 [DecodeUART]: Beginning UART Decoding...
2026/05/06 01:35:38 [DecodeUART]: UART Decoding complete
2026/05/06 01:35:38 [parseLogicPacket]: Logic packet seq=8
2026/05/06 01:35:38 [DecodeUART]: Beginning UART Decoding...
2026/05/06 01:35:38 [DecodeUART]: UART Decoding complete
2026/05/06 01:35:38 [parseLogicPacket]: Logic packet seq=9
2026/05/06 01:35:38 [DecodeUART]: Beginning UART Decoding...
2026/05/06 01:35:38 [DecodeUART]: UART Decoding complete
2026/05/06 01:35:38 [parseLogicPacket]: Logic packet seq=10
2026/05/06 01:35:38 [DecodeUART]: Beginning UART Decoding...
2026/05/06 01:35:38 [DecodeUART]: UART Decoding complete
2026/05/06 01:35:38 [parseLogicPacket]: Logic packet seq=11
2026/05/06 01:35:38 [DecodeUART]: Beginning UART Decoding...
2026/05/06 01:35:38 [DecodeUART]: UART Decoding complete
2026/05/06 01:35:38 [parseLogicPacket]: Logic packet seq=12
2026/05/06 01:35:38 [DecodeUART]: Beginning UART Decoding...
2026/05/06 01:35:38 [DecodeUART]: UART Decoding complete
2026/05/06 01:35:38 [parseLogicPacket]: Logic packet seq=13
2026/05/06 01:35:38 [DecodeUART]: Beginning UART Decoding...
2026/05/06 01:35:38 [DecodeUART]: UART Decoding complete
2026/05/06 01:35:38 [parseLogicPacket]: Logic packet seq=14
2026/05/06 01:35:38 [DecodeUART]: Beginning UART Decoding...
2026/05/06 01:35:38 [DecodeUART]: UART Decoding complete
2026/05/06 01:35:38 [parseLogicPacket]: Logic packet seq=15
2026/05/06 01:35:38 [DecodeUART]: Beginning UART Decoding...
2026/05/06 01:35:38 [DecodeUART]: UART Decoding complete
2026/05/06 01:35:38 [parseLogicPacket]: Logic packet seq=16
2026/05/06 01:35:38 [DecodeUART]: Beginning UART Decoding...
2026/05/06 01:35:38 [DecodeUART]: UART Decoding complete
2026/05/06 01:35:38 [parseLogicPacket]: Logic packet seq=17
2026/05/06 01:35:38 [DecodeUART]: Beginning UART Decoding...
2026/05/06 01:35:38 [DecodeUART]: UART Decoding complete
2026/05/06 01:35:38 [Run]: UART transfer over tx: t=4817300us TX=0x41
2026/05/06 01:35:38 [Run]: UART transfer over tx: t=4821500us TX=0x52
2026/05/06 01:35:38 [Run]: UART transfer over tx: t=4825600us TX=0x54
2026/05/06 01:35:38 [Run]: UART transfer over tx: t=4829800us TX=0x20
2026/05/06 01:35:38 [Run]: UART transfer over tx: t=4834000us TX=0x54
2026/05/06 01:35:38 [Run]: UART transfer over tx: t=4838100us TX=0x65
2026/05/06 01:35:38 [Run]: UART transfer over tx: t=4842300us TX=0x73
2026/05/06 01:35:38 [Run]: UART transfer over tx: t=4846500us TX=0x74
2026/05/06 01:35:38 [Run]: UART transfer over tx: t=4850600us TX=0x0D
2026/05/06 01:35:38 [Run]: UART transfer over tx: t=4854800us TX=0x0A
2026/05/06 01:35:38 [parseLogicPacket]: Logic packet seq=18
2026/05/06 01:35:38 [DecodeUART]: Beginning UART Decoding...
2026/05/06 01:35:38 [DecodeUART]: UART Decoding complete
2026/05/06 01:35:38 [parseLogicPacket]: Logic packet seq=19
2026/05/06 01:35:38 [DecodeUART]: Beginning UART Decoding...
2026/05/06 01:35:38 [DecodeUART]: UART Decoding complete
2026/05/06 01:35:38 [Run]: Capture complete.

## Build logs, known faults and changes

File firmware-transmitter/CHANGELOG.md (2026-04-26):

# Changelog for Firmware

Put all software notes/changelog stuff here. Try to format something like below to minimize git conflicts:

```
## <date, or commit hash>

<notes>

### Added

### Changed

### Removed

## <older date/hash>

...
```

This format is adopted from [keepachangelog.com](https://keepachangelog.com).

## 87d3902
- Added the looping code for transmitting UART, SPI, I2C, and CAN. 
- Changed the AutoRetransmission from Enable to Disable. I learned that this basically waits for an ACK signal from the CAN's "slave," but since we have no slave and are just sniffing the bus with the logic analyzer, we need to disable this so that it doesn't infinitely retransmit immediately when ACK is missing. 
- I kept the transmitting messages simple in strings instead of in HEX (except for CAN, since the max is 8 bytes). 
- Added the CAN filter
- We actually don't need interrupts. The blocking loop with HAL_MAX_DELAY actually will wait 49.7 days for a response on timeout lol, so this is just a blocking loop.  

## bb930f8

### Added
- Just did the initial CubeMX configuration for the transmitter STM32. 
- 168MHz HCLK: PLLM=4, PLLN=168, PLLP=2, HSE=8MHz - same as receiver
- CAN1: PB8/PB9, 500kbps (PSC=6, BS1=11TQ, BS2=2TQ), Normal mode, AutoBusOff, AutoRetransmission
- USART1: PA9 TX, 115200 baud, 8-bit, no parity, TX only
- SPI2: PB10 SCK, PC1 MOSI, PC2 MISO, Full-Duplex Master, 8-bit, Prescaler=256 (~164kHz)
- I2C1: PB6 SCL, PB7 SDA, Standard Mode 100kHz
- USART2: PA2/PA3, 115200 baud, ST-Link debug
- No USB or DMA since the transmitter only generates test signals in a loop
- Firmware (main.c loop) not yet writte

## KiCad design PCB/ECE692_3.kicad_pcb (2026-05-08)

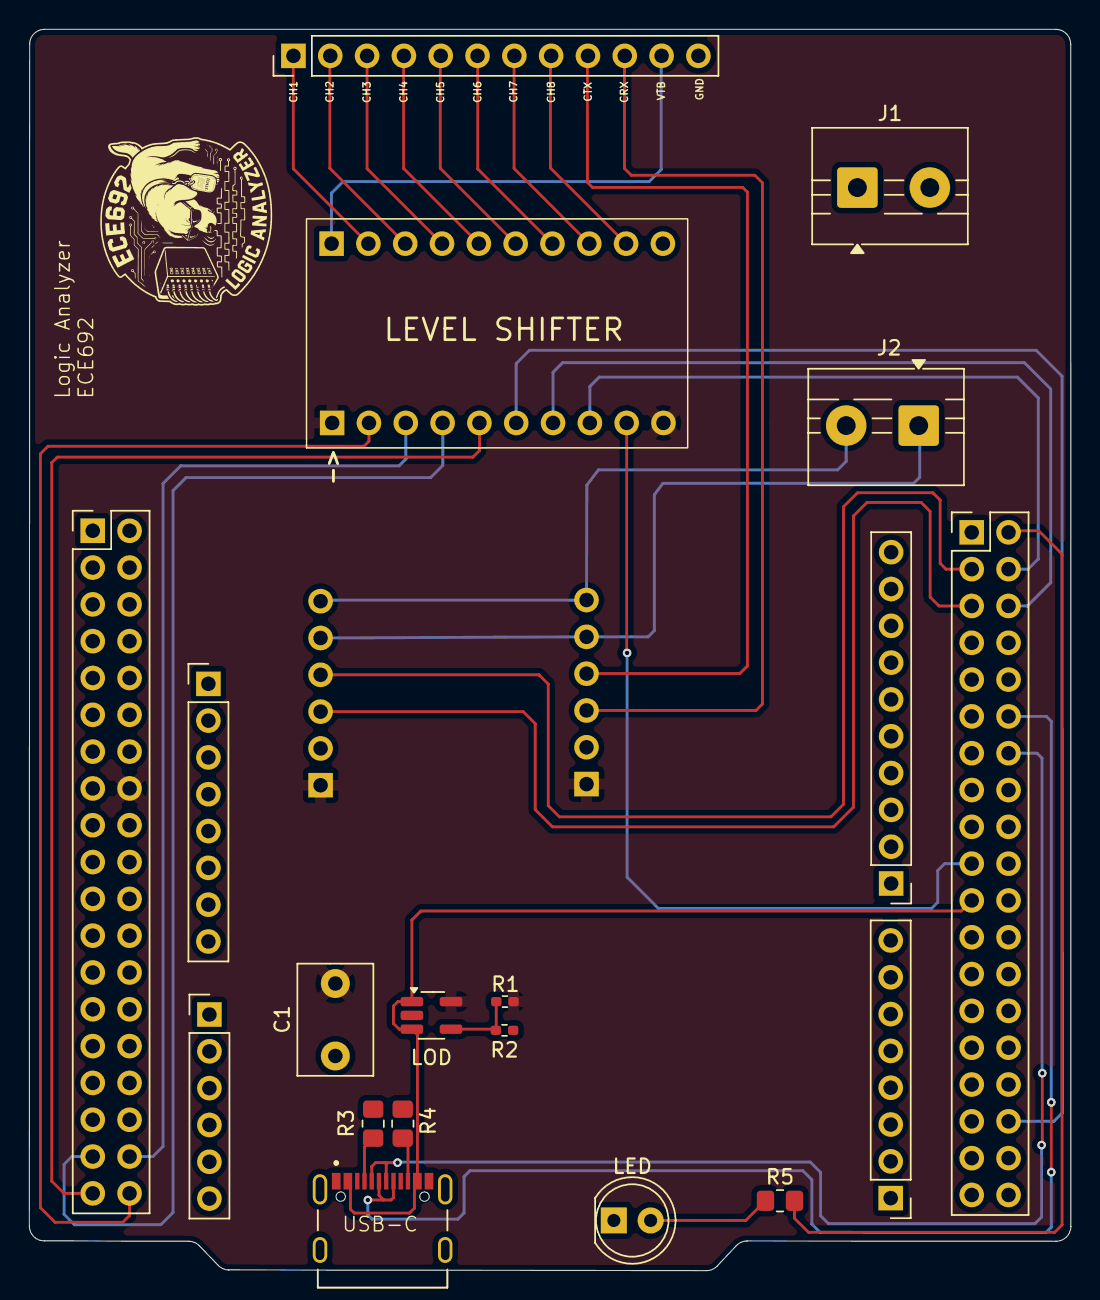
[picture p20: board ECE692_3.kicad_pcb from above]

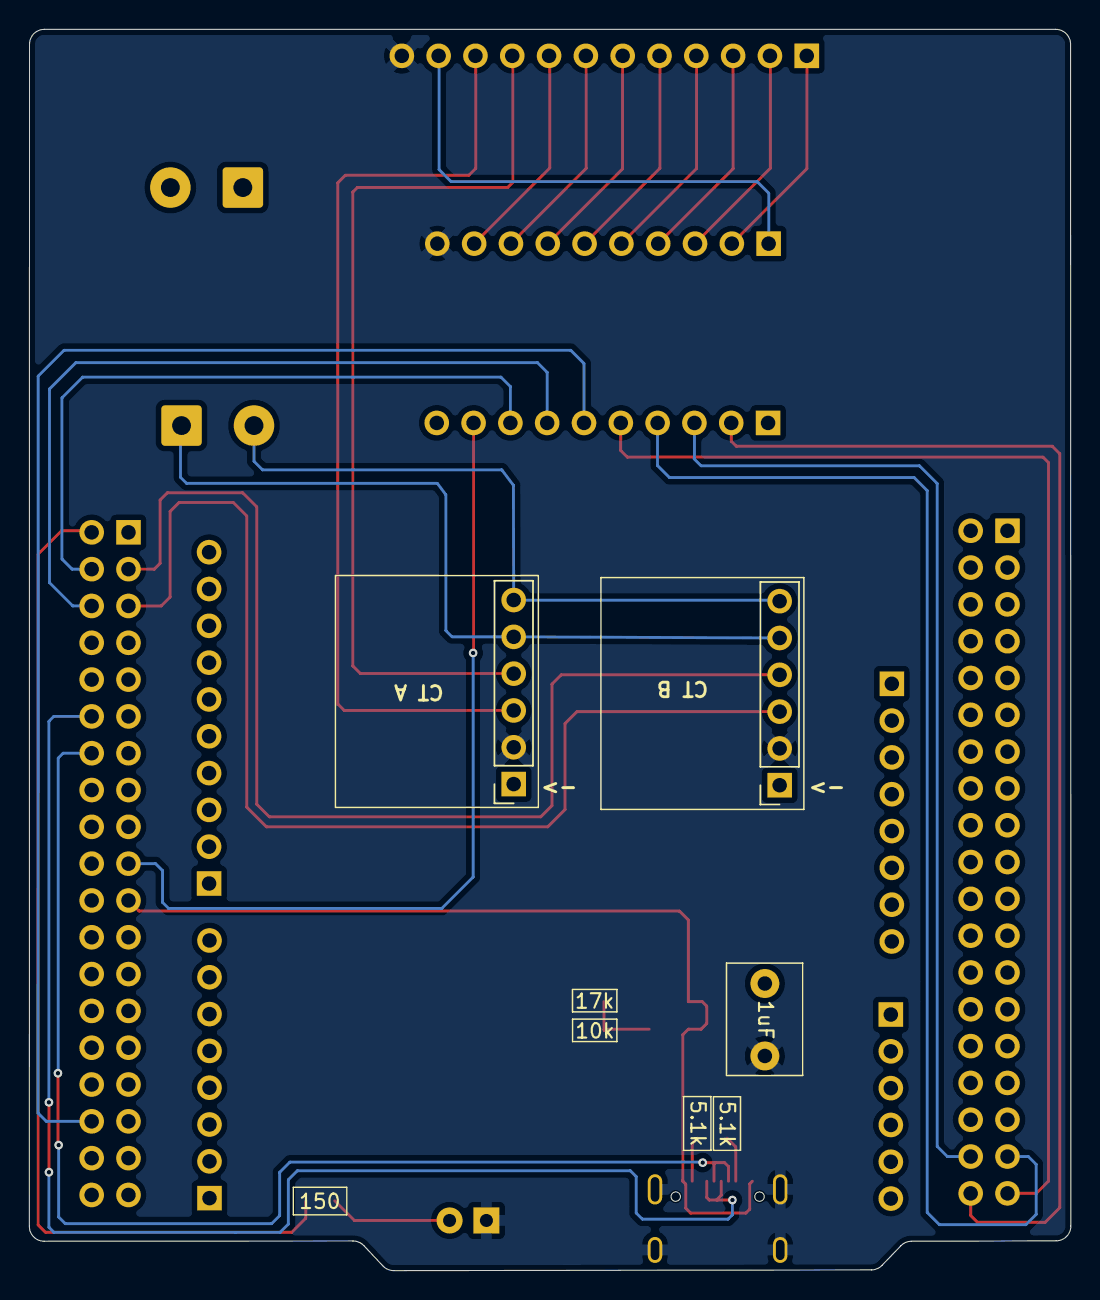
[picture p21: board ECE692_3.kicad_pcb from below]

Board: 2 copper layers, 71.9 x 85.6 mm, 17 parts (2 on the bottom side), 33 nets.

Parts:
C1: 1uF; C_Disc_D7.5mm_W5.0mm_P5.00mm
D1: LED; LED_D5.0mm
J1, J2: Screw_Terminal_01x02; TerminalBlock_MaiXu_MX126-5.0-02P_1x02_P5.00mm
J1#2: TYPE-C_16PIN_2MD__073_; SHOUHAN_TYPE-C_16PIN_2MD__073_
J2#2: Conn_01x12; PinHeader_1x12_P2.54mm_Vertical
R1: 17k; R_0402_1005Metric_Pad0.72x0.64mm_HandSolder
R2: 10k; R_0402_1005Metric_Pad0.72x0.64mm_HandSolder
R3, R4: 5.1k; R_0805_2012Metric_Pad1.20x1.40mm_HandSolder
R5: 150; R_0805_2012Metric_Pad1.20x1.40mm_HandSolder
U1: CAN_BUS_TRANSCEIVER1; PinSocket_1x06_P2.54mm_Vertical
U2: CAN_BUS_TRANSCEIVER2; PinSocket_1x06_P2.54mm_Vertical
U3: LOD; SOT-23-5_HandSoldering
U4: LEVEL_SHIFTER
U5, U6: NUCLEO-F446RE; PinHeader_2x19_P2.54mm_Vertical

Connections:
3V3: C1.1, R1.1, U1.1 (3V3), U2.1 (3V3), U3.5 (VOUT), U4.1 (VCCA), U4.10 (OE), U5.16 (CN7_+3V3)
CH1: U4.2 (A1), U5.38 (PC0/PB8)
CH2: U4.3 (A2), U5.36 (PC1/PB9)
CH3: U4.4 (A3), U5.35 (PC2)
CH4: U4.5 (A4), U5.37 (PC3)
CH5: U4.6 (A5), U6.34 (PC4)
CH6: U4.7 (A6), U6.6 (PC5)
CH7: U4.8 (A7), U6.4 (PC6)
CH8: U4.9 (A8), U6.19 (PC7)
CRX: U2.4 (CRX), U6.3 (PB8)
CRX_TB: J2#2.10, U1.3 (CTX)
CTX: U2.3 (CTX), U6.5 (PB9)
CTX_TB: J2#2.9, U1.4 (CRX)
D+: J1#2.A6 (DP1), J1#2.B6 (DP2), U6.12 (PA12)
D-: J1#2.A7 (DN1), J1#2.B7 (DN2), U6.14 (PA11)
GND: C1.2, D1.1 (K), J1#2.A1_B12 (GND_A), J1#2.B1_A12 (GND_B), J1#2.SH1 (SHIELD), J1#2.SH2 (SHIELD), J1#2.SH3 (SHIELD), J1#2.SH4 (SHIELD), J2#2.12, R2.2, R3.1, R4.2, U1.2 (GND), U2.2 (GND), U3.2 (GND), U4.20 (GND)
unnamed: D1.2 (A), R5.1
unnamed: J1#2.A5 (CC1), R3.2
unnamed: J1#2.B5 (CC2), R4.1
unnamed: J1.1, J2.1, U1.5 (CANH), U2.5 (CANH)
unnamed: J1.2, J2.2, U1.6 (CANL), U2.6 (CANL)
unnamed: R1.2, R2.1, U3.4 (ADJ)
unnamed: R5.2, U6.2 (PC8)
TB_CH1: J2#2.1, U4.12 (B1)
TB_CH2: J2#2.2, U4.13 (B2)
TB_CH3: J2#2.3, U4.14 (B3)
TB_CH4: J2#2.4, U4.15 (B4)
TB_CH5: J2#2.5, U4.16 (B5)
TB_CH6: J2#2.6, U4.17 (B6)
TB_CH7: J2#2.7, U4.18 (B7)
TB_CH8: J2#2.8, U4.19 (B8)
VBUS: J1#2.A4_B9 (VBUS_A), J1#2.B4_A9 (VBUS_B), U3.1 (5V), U3.3 (EN), U6.21 (PA9)
V_TB: J2#2.11, U4.11 (VCCB)

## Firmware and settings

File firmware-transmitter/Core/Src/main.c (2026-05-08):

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
/* Includes ------------------------------------------------------------------*/
#include "main.h"

/* USER CODE BEGIN Includes */
#include <string.h>
/* USER CODE END Includes */

CAN_HandleTypeDef hcan1;

I2C_HandleTypeDef hi2c1;

SPI_HandleTypeDef hspi2;

UART_HandleTypeDef huart1;
UART_HandleTypeDef huart2;

/* USER CODE BEGIN PV */

// This is a dummy address; since our logic analyzer is just a sniffer,
// the slave address doesn't even matter. The ACK and timeout issues will
// be handled later below.
#define I2C_DEVICE_ADDRESS 0x52
/* USER CODE END PV */

void SystemClock_Config(void);
static void MX_GPIO_Init(void);
static void MX_USART2_UART_Init(void);
static void MX_CAN1_Init(void);
static void MX_I2C1_Init(void);
static void MX_SPI2_Init(void);
static void MX_USART1_UART_Init(void);
/**
  * @brief  The application entry point.
  * @retval int
  */
int main(void)
{

  /* MCU Configuration--------------------------------------------------------*/

  /* Reset of all peripherals, Initializes the Flash interface and the Systick. */
  HAL_Init();

  /* Configure the system clock */
  SystemClock_Config();

  /* Initialize all configured peripherals */
  MX_GPIO_Init();
  MX_USART2_UART_Init();
  MX_CAN1_Init();
  MX_I2C1_Init();
  MX_SPI2_Init();
  MX_USART1_UART_Init();
  /* USER CODE BEGIN 2 */
  HAL_Delay(1000);

  // Start CAN

  CAN_FilterTypeDef canFilter;
  canFilter.FilterBank = 0;
  canFilter.FilterMode = CAN_FILTERMODE_IDMASK;
  canFilter.FilterScale = CAN_FILTERSCALE_32BIT;
  canFilter.FilterIdHigh = 0x0000;
  canFilter.FilterIdLow = 0x0000;
  canFilter.FilterMaskIdHigh = 0x0000;
  canFilter.FilterMaskIdLow = 0x0000;
  canFilter.FilterFIFOAssignment = CAN_RX_FIFO0; /* The data will be received in FIFO0 */
  canFilter.FilterActivation = ENABLE;
  HAL_CAN_ConfigFilter(&hcan1, &canFilter); //configures the CAN reception filter
  HAL_CAN_Start(&hcan1);


  /* USER CODE END 2 */

  /* Infinite loop */
  /* USER CODE BEGIN WHILE */
  while (1)
  {

	  //UART
	  	  uint8_t uart_msg[] = "UART Test\r\n";
	  	  HAL_UART_Transmit(&huart1, uart_msg, sizeof(uart_msg)-1, HAL_MAX_DELAY);

	  	  //SPI
	  	  uint8_t spi_msg[] = "SPI Test"; //No new lines here bc SPI has no concept of new lines.
	  	  HAL_SPI_Transmit(&hspi2, spi_msg, sizeof(spi_msg)-1, HAL_MAX_DELAY);

	  	  //I2C
	  	  uint8_t i2c_msg[] = "I2C Test";

	  	  //Here, instead of MAX_DELAY, we set the timeout to 100
	  	  // This is bc I2C waits for ACK, but since there's no slave, there will be no ACK
	  	  // So we wait for 100ms and move on so there's no block
	  	  HAL_I2C_Master_Transmit(&hi2c1, I2C_DEVICE_ADDRESS <<1, i2c_msg, sizeof(i2c_msg)-1, 100);

	  	  //Deinitialize I2C
	  	  HAL_I2C_DeInit(&hi2c1);

	  	  //reinitialize I2C
	  	  HAL_I2C_Init(&hi2c1);

	  	  //CAN
	  	  CAN_TxHeaderTypeDef txHeader;
	  	  //we can do a custom message for CAN, but the max is 8 bytes
	  	  // so it's better to keep in hex
	  	  uint8_t can_msg[] = {0xCA, 0xFE, 0xBA, 0xBE, 0xDE, 0xAD, 0xBE, 0xEF};
	  	  uint32_t txMailbox; //the number of the mailbox that transmitted the CAN msg
	  	  txHeader.StdId = 0x123;
	  	  txHeader.RTR = CAN_RTR_DATA;
	  	  txHeader.IDE = CAN_ID_STD;
	  	  txHeader.DLC = 8;
	  	  HAL_CAN_AddTxMessage(&hcan1, &txHeader, can_msg, &txMailbox);
	  	  HAL_Delay(500);
    /* USER CODE END WHILE */



    /* USER CODE BEGIN 3 */
  }
  /* USER CODE END 3 */
}

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


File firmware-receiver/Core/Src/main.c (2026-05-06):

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
/* Includes ------------------------------------------------------------------*/
#include "main.h"
#include "usb_device.h"

/* USER CODE BEGIN Includes */
#include "usbd_cdc_if.h"
#include <string.h>
/* USER CODE END Includes */

CAN_HandleTypeDef hcan1;

TIM_HandleTypeDef htim1;
DMA_HandleTypeDef hdma_tim1_up;

UART_HandleTypeDef huart2;

/* USER CODE BEGIN PV */
#define DATA_CHUNK 512
#define DMA_BUF_SIZE (DATA_CHUNK*2) // 1024 bytes

//The DMA will dump the GPIO samples here
//I'm using the ping-pong idea we talked about but with the circular array
//So we have one array of 1024 uint8_t elements holding 2 chunks of 512 samples
//Each sample is 1 byte capturing PC0-PC7 (all 8 channels fit into low byte)

//Basically, when the USB is transmitting, new samples still need somewhere to go
//So the idea is, when the DMA is half full, the USB can transmit samples
//from position 0 while new samples get written to position 512 and onward.
uint8_t dma_buf[DMA_BUF_SIZE];
static uint8_t logic_seq_num = 0;
static uint8_t can_seq_num = 0;
volatile uint8_t send_first_half = 0;
volatile uint8_t send_second_half = 0;
/* USER CODE END PV */

void SystemClock_Config(void);
static void MX_GPIO_Init(void);
static void MX_DMA_Init(void);
static void MX_TIM1_Init(void);
static void MX_USART2_UART_Init(void);
static void MX_CAN1_Init(void);
/* USER CODE BEGIN PFP */
void send_logic_packet(uint8_t *data_ptr);
void myHalfCallback(DMA_HandleTypeDef *hdma);
void myCpltCallback(DMA_HandleTypeDef *hdma);
/* USER CODE END PFP */

/**
  * @brief  The application entry point.
  * @retval int
  */
int main(void)
{

  /* MCU Configuration--------------------------------------------------------*/

  /* Reset of all peripherals, Initializes the Flash interface and the Systick. */
  HAL_Init();

  /* Configure the system clock */
  SystemClock_Config();

  /* Initialize all configured peripherals */
  MX_GPIO_Init();
  MX_DMA_Init();
  MX_TIM1_Init();
  MX_USART2_UART_Init();
  MX_USB_DEVICE_Init();
  MX_CAN1_Init();
  /* USER CODE BEGIN 2 */
  // We'll use the bxCAN peripheral for CAN
  // The thing is tho, it rejects everything by default.
  // So the filter below lets it know which data to let in
  //printf("Hello World"); debug statement
  CAN_FilterTypeDef canFilter;

  canFilter.FilterBank = 0; //Bank 0
  canFilter.FilterMode = CAN_FILTERMODE_IDMASK;
  canFilter.FilterScale = CAN_FILTERSCALE_32BIT;
  canFilter.FilterIdHigh = 0x0000;
  canFilter.FilterIdLow = 0x0000;
  canFilter.FilterMaskIdHigh = 0x0000;
  canFilter.FilterMaskIdLow = 0x0000;
  canFilter.FilterFIFOAssignment = CAN_RX_FIFO0;
  canFilter.FilterActivation = ENABLE;

  if (HAL_CAN_ConfigFilter(&hcan1, &canFilter) != HAL_OK)
  {
    Error_Handler();
  }

  HAL_CAN_Start(&hcan1);

  //Fires an RX interrupt when a frame arrives in the receive FIFO
  HAL_CAN_ActivateNotification(&hcan1, CAN_IT_RX_FIFO0_MSG_PENDING);

  //To let the USB breathe
  HAL_Delay(1000);
  //Start TIM1 - 1MHz for DMA sampling
  HAL_TIM_Base_Start(&htim1);

  hdma_tim1_up.XferHalfCpltCallback = myHalfCallback;
  hdma_tim1_up.XferCpltCallback = myCpltCallback;
  //Start DMA - reads the GPIOC -> IDR into dma_buf on every TIM1 tick, so 1us
  HAL_DMA_Start_IT(&hdma_tim1_up, (uint32_t)&GPIOC->IDR,
		          (uint32_t)dma_buf, DMA_BUF_SIZE);

  //Enable the DMA request on TIM1 update event
  TIM1-> DIER |= TIM_DIER_UDE;
  /* USER CODE END 2 */

  /* Infinite loop */
  /* USER CODE BEGIN WHILE */
  while (1)
  {
	  	/* Testing Code
	    // Toggle the Green LED (PA5) so we have a signal to "sniff"
	    HAL_GPIO_TogglePin(GPIOA, GPIO_PIN_5);

	    // Create and send a test CAN message to ourselves
	    CAN_TxHeaderTypeDef txHeader;
	    uint8_t testData[] = {0xDE, 0xAD, 0xBE, 0xEF, 0xCA, 0xFE, 0xBA, 0xBE};
	    uint32_t txMailbox;

	    txHeader.StdId = 0x123;
	    txHeader.RTR = CAN_RTR_DATA;
	    txHeader.IDE = CAN_ID_STD;
	    txHeader.DLC = 8;

	    HAL_CAN_AddTxMessage(&hcan1, &txHeader, testData, &txMailbox);

	    // Wait half a second
	    HAL_Delay(2000);
		*/
	  if (send_first_half)
	  {
		  send_first_half = 0;
		  send_logic_packet(&dma_buf[0]);
	  }
	  if (send_second_half)
	  {
		  send_second_half = 0;
		  send_logic_packet(&dma_buf[DATA_CHUNK]);
	  }
    /* USER CODE END WHILE */

    /* USER CODE BEGIN 3 */
  }
  /* USER CODE END 3 */
}

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
/* USER CODE BEGIN 4 */

//For sending words over UART
//int __io_putchar(int ch) {
//  HAL_UART_Transmit(&huart2, (uint8_t *)&ch, 1, 0xFFFF);
//  return ch;
//}

// Fires when DMA has filled the buffer with 512 samples (512 bytes)
// Sends the raw samples over USB to PC where our Go and Python apps will take over
// CDC_Transmit_FS handles splitting into 64 byte USB transactions internally
// We just pass the full 516 byte packet and the USB stack takes care of it
// Format: [0xAA][0xBB][seq#][512 uint8 samples=512 bytes][checksum]
void send_logic_packet(uint8_t *data_ptr)
{
	//made this static so it persists during USB transfer
	static uint8_t packet[516]; // 3 header + 512 data + 1 checksum
	packet[0] = 0xAA;
	packet[1] = 0xBB;
	packet[2] = logic_seq_num++;

	//I found that memcpy works much faster than a typical for loop
	//it's optimized at the hardware level
	memcpy(&packet[3], data_ptr, DATA_CHUNK);

    uint8_t checksum = 0;
	for (int i = 0; i < 515; i++) {
		checksum ^= packet[i];
	}
	packet[515] = checksum;

	//Monitor for overflows here!
	if (HAL_UART_Transmit(&huart2, packet, 516, 100)!= HAL_OK)
	{
		//This means that the PC isn't reading fast enough
	    static uint32_t dropped_packets = 0;
	    dropped_packets++;
	}
}
//void HAL_DMA_XferHalfCpltCallback(DMA_HandleTypeDef *hdma) {
//    if (hdma == &hdma_tim1_up) {
//    	send_logic_packet(&dma_buf[0]);
//    }
//}
//
//void HAL_DMA_XferCpltCallback(DMA_HandleTypeDef *hdma) {
//    if (hdma == &hdma_tim1_up) {
//    	send_logic_packet(&dma_buf[DATA_CHUNK]);
//    }
//}

void myHalfCallback(DMA_HandleTypeDef *hdma) {
    HAL_GPIO_TogglePin(GPIOA, GPIO_PIN_5);
    send_first_half = 1;
}

void myCpltCallback(DMA_HandleTypeDef *hdma) {
    send_second_half = 1;
}
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

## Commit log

2026-04-23 Initial Python GUI updates including TCP socket connection to the eventual Go decoder as well as a display for the GUI. Feel free to try it out. I'll update the CHANGELOG soon.
2026-04-24 Added a clear option for two measurements, made the vertical markers cleaner, it just looks a little neater now. shoutout to Jean Claude
    [receiver.kicad_sch, transmitter.kicad_sch]
2026-04-24 removed PCB folder from the GUI branch
    [receiver.kicad_sch, transmitter.kicad_sch]
2026-04-25 Modified some stuff, and did some routing
    - Replaced the rectangle with the STM nucleo board shape
    - added the level shifter symbol and footprint
    [ECE692.kicad_pcb, ECE692.kicad_sch]
2026-04-28 Fixed sequence tracking, got the test scripts working with Arnav's socat script. I'll add a small sample of the output in the CHANGELOG.
    [test.py]
2026-04-29 added the SPI decoder with custom SPI modes and optional CS support
2026-04-29 updated serial.go to accomodate for spi decoder.
2026-04-29 Added docs for how uart decoder works
2026-04-29 Added Sample Rate as required cli argument
    - pass in using `-sr xyz`
2026-05-01 updated test.py to support SPI testing and made a few tweaks to the SPI decoder. There was a slight masking issue in the UART decoder, so fixed that as well.
    [test.py]
2026-05-02 added LED toggles
2026-05-06 fixed a bunch of packet alignment issues, sequence number cycle back issue, timestamp problems, etc. sample output looks solid, but if we want to eliminate even more noise fluctuations, we have to sa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
2026-05-06 got the GUI to display uart signals, tho not very reliable rn. the decoded frames dont show yet. Added a few things. We can now forward raw logic packets and ANN decoded frames from Go to Python over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
    [display.py, gui.py, packets.py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]
2026-05-06 made a few changes to the glitch filter and decoded frames display. it now shows the annotations on top of the waveforms, and it seems to be mostly correct.
    [display.py, gui.py, packets.py]
2026-05-08 updated README and added enclosure files.
    [Enclosure.stl, Lid.stl]

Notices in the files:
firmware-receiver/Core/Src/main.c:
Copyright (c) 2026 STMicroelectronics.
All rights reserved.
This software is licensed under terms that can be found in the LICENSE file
